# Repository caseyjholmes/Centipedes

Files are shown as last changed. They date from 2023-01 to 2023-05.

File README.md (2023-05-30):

# Centipedes
Quad-purpose Manual and CV controlled 1-100 Burst Generator, Voltage Controlled Master Clock, Voltage Controlled Gate Crasher and Voltage Controlled Clock Mult/Divide Eurorack Module with PSI EITHER WAY power in 4HP.

The module utilizes a ATMEGA328P micrcontroller. The firmware is included before and after compile. You can program with arduino or AVRISPMKII or ebay clone.

Do not populate R19. You can if you want, but it's not necessary. 
Otherwise, this is a straight forward Eurorack format synthesizer module build. 

Enjoy! 
-Casey

5-22-2023 update
Centipedes will now be taking on four individual modes that work with the posted PCB. I will be posting four software routines for each. 
The first of which is a new Centipedes V3 Firmware. It will be uploaded today 5-22-23

There is now one mode for each software file set. No more easter eggs or hidden features. Each mode is stand alone face value. No menus or bugs.

Panels will be provided for each alternate software mode  

The first and updated software mode is NOW posted above on this page.                                                                             
The second, "Centipedes Voltage Controlled Matser Clock" and its associated front panel, is NOW available here:                                                                     
https://github.com/caseyjholmes/Centipedes_Master_Clock

The third mode, "Centipedes Voltage Controled Gate Crasher" and its associated alternate front panel is NOW available here:                                                                   
https://github.com/caseyjholmes/Centipedes_Gate_Crasher

The fourth mode, "Centipedes Voltage Controlled Clock Divider Multiplier" is SOON to be available here:                                                             
https://github.com/caseyjholmes/Centipedes_Clock_Mult_Div

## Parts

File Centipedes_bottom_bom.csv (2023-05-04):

Comment | Designator | Footprint | LCSC Part #
1M | IC1 R11 | R0603
1k | R15 | R0603
2.2k bead | L1 | 0603
10K | R1 | R0603
10k | R12 R14 R16 | R0603
10n | C5 C6 | C0603K
18p | C11 C12 | C0603K
20MHZ | Q1 | HC49UP
22uf | C1 C2 C8 | PANASONIC_C
100k | R2 R3 R4 R5 R6 R7 R8 R9 R10 R13 | R0603
100n | C3 C7 C10 C13 C14 | C0603K
470n | C4 | C0603K
3904 | T1 T2 | SOT23-BEC
ATMEGA328P-AU | IC4 | TQFP32-08
MB1S | D1 | SOIC-4
MCP6002 | IC3 | SO08
REG1117 5.0V | IC2 | SOT223

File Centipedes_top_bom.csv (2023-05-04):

Comment | Designator | Footprint | LCSC Part #
10k | R19 | R0603
200r | R17 R18 | R0603

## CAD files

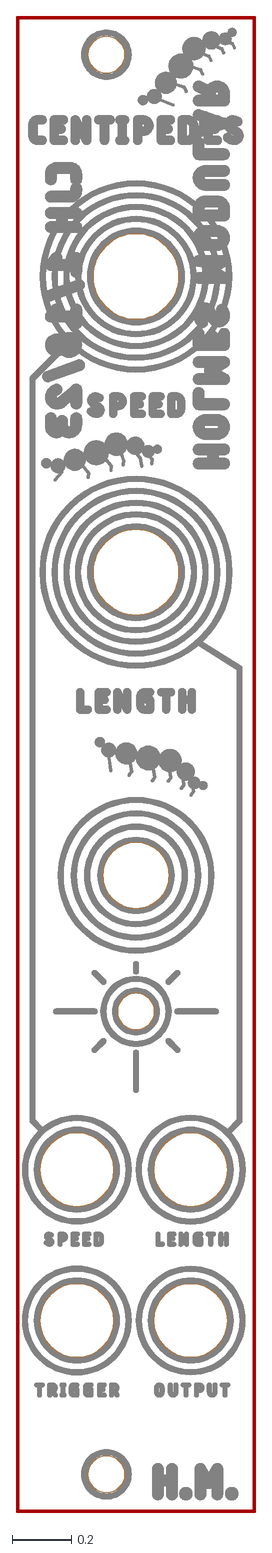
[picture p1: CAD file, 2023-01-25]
Centipedes PANEL.dxf
0.81 x 5.06

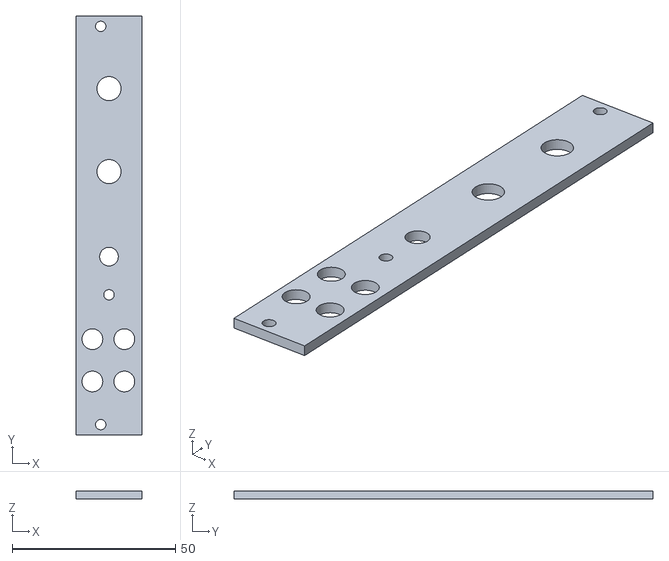
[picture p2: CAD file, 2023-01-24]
3d printable panel centi.stl
20.3 x 128.3 x 2.54

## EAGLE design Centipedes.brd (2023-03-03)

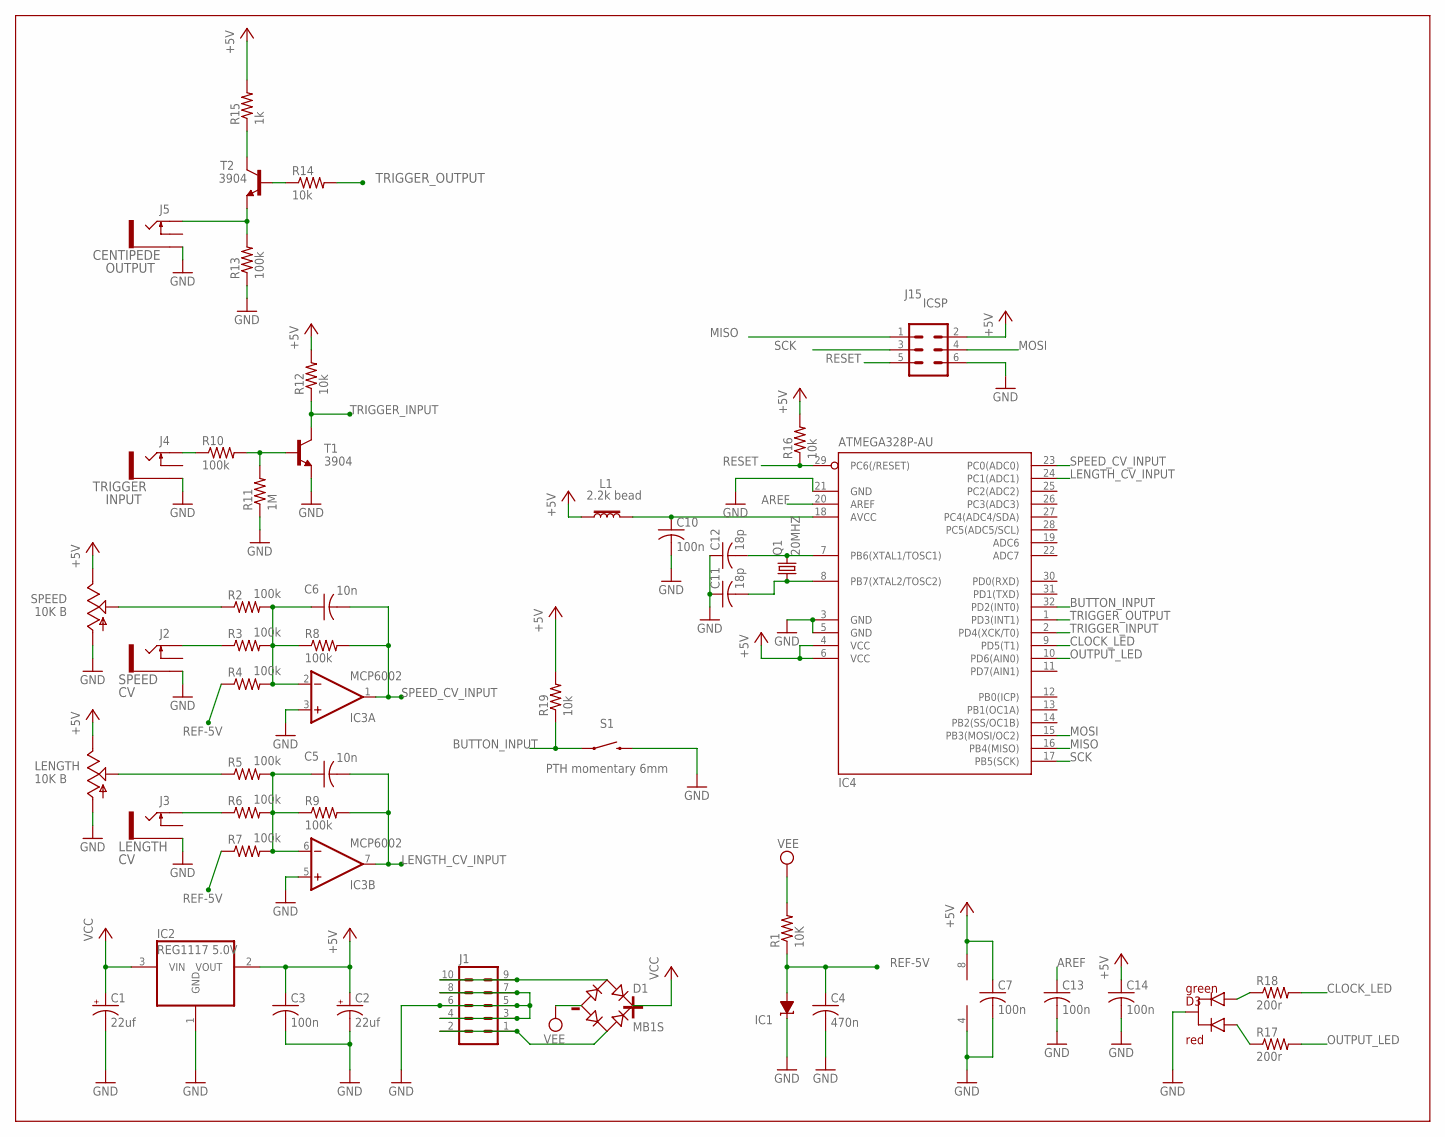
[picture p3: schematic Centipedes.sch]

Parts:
C1, C2: 22uf; PANASONIC_C
C3, C7, C10, C13, C14: 100n; C0603K
C4: 470n; C0603K
C5, C6: 10n; C0603K
C11, C12: 18p; C0603K
D1: MB1S; SOIC-4
D3: LED-DUALCOLOR3MM-THROUGH-HOLE; LED-DUALCOLOR-3MM
IC1: LM4041A12DBZ; DBZ_R-PDSO-G3
IC2: REG1117 5.0V; SOT223
IC3: MCP6002; SO08
IC4: ATMEGA328P-AU; TQFP32-08
J1: MA05-2
J2, J3, J4, J5: THONKICONNNEW; WQP-PJ301M-12_JACK
J15: ICSP; MA03-2
L1: 2.2k bead; 0603
LENGTH: 10K B; 9MM_SNAP-IN_POT
Q1: 20MHZ; HC49UP
R1: 10K; R0603
R2, R3, R4, R5, R6, R7, R8, R9, R10, R13: 100k; R0603
R11: 1M; R0603
R12, R14, R16, R19: 10k; R0603
R15: 1k; R0603
R17, R18: 200r; R0603
S1: PTH momentary 6mm; TACTILE_SWITCH_PTH_6.0MM
SPEED: 10K B; 9MM_SNAP-IN_POT
T1, T2: 3904; SOT23-BEC

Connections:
+5V: C2.+, C3.1, C7.1, C14.1, IC2.2 (VOUT), IC3.8 (V+), IC4.4 (VCC), IC4.6 (VCC), J15.2, L1.1, LENGTH.3 (E), R12.2, R15.2, R16.2, R19.2, SPEED.3 (E)
AREF: C13.1, IC4.20 (AREF)
BUTTON_INPUT: IC4.32 (PD2(INT0)), R19.1, S1.1
CLOCK_LED: IC4.9 (PD5(T1)), R18.2
GND: C1.-, C2.-, C3.2, C4.2, C7.2, C10.2, C11.1, C12.1, C13.2, C14.2, D3.K, IC1.1 (C), IC2.1 (GND), IC3.3 (+IN), IC3.4 (V-), IC3.5 (+IN), IC4.3 (GND), IC4.5 (GND), IC4.21 (GND), J1.3, J1.4, J1.5, J1.6, J1.7, J1.8, J2.P$3_SLEEVE (SLEEVE), J3.P$3_SLEEVE (SLEEVE), J4.P$3_SLEEVE (SLEEVE), J5.P$3_SLEEVE (SLEEVE), J15.6, LENGTH.1 (A), R11.1, R13.1, S1.3 (2), SPEED.1 (A), T1.E; also elsewhere on the board
LENGTH_CV_INPUT: C5.2, IC3.7 (OUT), IC4.24 (PC1(ADC1)), R9.2
MISO: IC4.16 (PB4(MISO)), J15.1
MOSI: IC4.15 (PB3(MOSI/OC2)), J15.4
unnamed: LENGTH.2 (S), R5.1
unnamed: C5.1, IC3.6 (-IN), R5.2, R6.2, R7.2, R9.1
unnamed: J3.P$1_TIP (TIP), R6.1
unnamed: D1.~2 (AC2), J1.1, J1.2
unnamed: D1.~1 (AC1), J1.9, J1.10
unnamed: J4.P$1_TIP (TIP), R10.1
unnamed: C6.1, IC3.2 (-IN), R2.2, R3.2, R4.2, R8.1
unnamed: R10.2, R11.2, T1.B
unnamed: J2.P$1_TIP (TIP), R3.1
unnamed: R2.1, SPEED.2 (S)
unnamed: J5.P$1_TIP (TIP), R13.2, T2.E
unnamed: R15.1, T2.C
unnamed: R14.1, T2.B
unnamed: C12.2, IC4.7 (PB6(XTAL1/TOSC1)), Q1.2
unnamed: C11.2, IC4.8 (PB7(XTAL2/TOSC2)), Q1.1
unnamed: D3.A1, R18.1
unnamed: C10.1, IC4.18 (AVCC), L1.2
unnamed: D3.A2, R17.1
OUTPUT_LED: IC4.10 (PD6(AIN0)), R17.2
REF-5V: C4.1, IC1.2 (A), R1.1, R4.1, R7.1
RESET: IC4.29 (PC6(/RESET)), J15.5, R16.1
SCK: IC4.17 (PB5(SCK)), J15.3
SPEED_CV_INPUT: C6.2, IC3.1 (OUT), IC4.23 (PC0(ADC0)), R8.2
TRIGGER_INPUT: IC4.2 (PD4(XCK/T0)), R12.1, T1.C
TRIGGER_OUTPUT: IC4.1 (PD3(INT1)), R14.2
VCC: C1.+, D1.+, IC2.3 (VIN)
VEE: D1.-, R1.2; also elsewhere on the board

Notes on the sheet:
TRIGGER
SPEED
LENGTH
CENTIPEDE
OUTPUT
INPUT
red
green

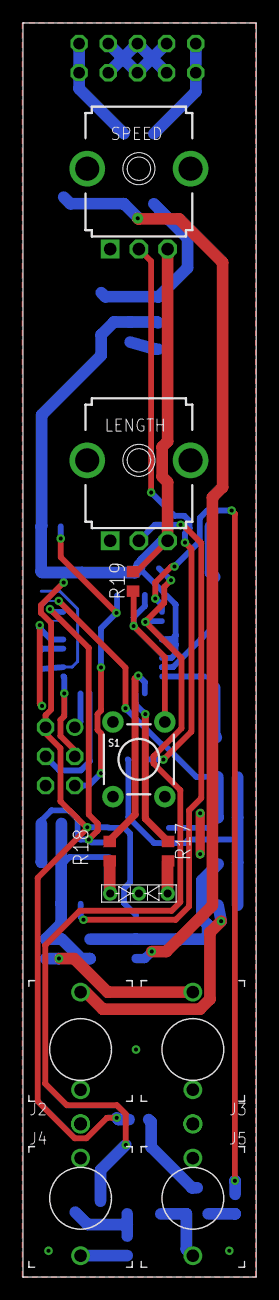
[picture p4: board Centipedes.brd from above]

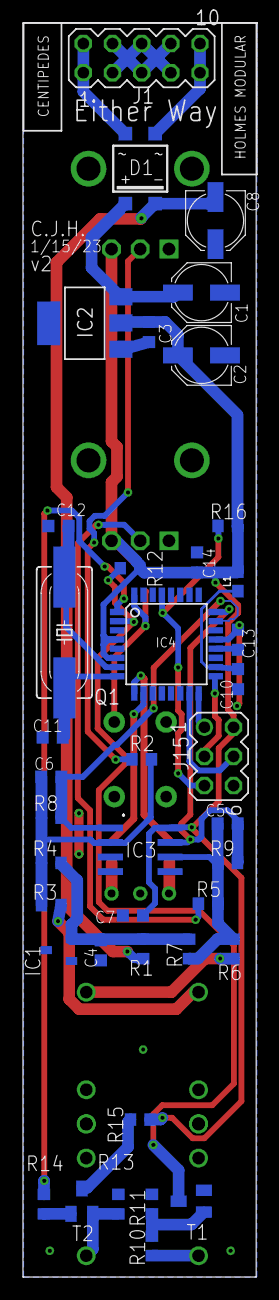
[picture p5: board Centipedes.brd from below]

Board: 2 copper layers, 20.3 x 109.2 mm, 51 parts (40 on the bottom side), 35 nets.

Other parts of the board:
C8: 22uf; PANASONIC_C

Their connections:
GND: C8.+; also elsewhere on the board
VEE: C8.-; also elsewhere on the board

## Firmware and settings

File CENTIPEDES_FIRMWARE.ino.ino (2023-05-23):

//CASEY HOLMES - HOLMES MODULAR - "CENTIPEDES" REV3 - 5/21/23

//constants
const int buttonPin = 2;                       //button pin
const int output = 3;                          //output transistor on pin 3
const int outputLed = 6;                       //red output LED
const int clockLed =  5;                       //green clock led
const int clockPin = 4;                        //clock input transistor pin
long debounce = 20;                            //debounce time no flicker

// Variables
int buttonVal = 0;                             //variable to store current state of the button, usable in interrupt 
int buttonLast = 0;                            //variable to store last state of button
int clockState = 0;                            //variable to store current clock status
int buttonState = 0;                           //varable to store current state of button
bool isOn = true;                              //variable to store state of master duty clock cycle
long btnDnTime;                                //time button was pressed down
long btnUpTime;                                //time button was released
boolean ignoreUp = false;                      //weather ignore button release because press + hold was triggered
unsigned long loopspot = 0;                    //loops pot read variable
unsigned long speedpot =0;                     //speed pot read variable

void setup() {
pinMode(buttonPin, INPUT_PULLUP);              //initialize the pushbutton pin as an input with a internal pullup resistor
pinMode(output, OUTPUT);                       //initialize output transistor
pinMode(outputLed, OUTPUT);                    //initialize output LED as output
digitalWrite(outputLed, 0);                    //initialize output LED as off
pinMode(clockLed, OUTPUT);                     //initialize the LED pin as an output:
digitalWrite(clockLed, 0);                     //initialize cock LED as off
pinMode(clockPin, INPUT);                      //initialize clock pin as input
}

//function for button pressed (triggering a single centipede)
void shortpress() {                            //button was momentarily pressed
digitalWrite(outputLed, 1);                    //turn on LED green indicating button press.
digitalWrite(clockLed, 1);                     //turn on the other color LED
loopspot = map(analogRead(A1), 0, 1023, 100, 1);//read and map pot on A1 into loopspot variable
for (int b = 0; b < loopspot; b++) {           //run for loop for loopspot amount of times
    speedpot = map(analogRead(A0), 0, 1023, 5, 1000);//read and scale Analog 0 into speedpot
    digitalWrite(outputLed, 0);                //turn on output led
    digitalWrite(output, 1);                   //turn on output
    delay(speedpot);                           //wait here for length of speed pot variable
    digitalWrite(outputLed, 1);                //turn off the output LED
    digitalWrite(output, 0);                   //turn off the output
    delay(speedpot);                           //wait here for length of speed pot variable
    }
digitalWrite(outputLed, 0);                    //keep red output led off
digitalWrite(output, 0);                       //turn off the output
digitalWrite(clockLed, 0);                     //keep the red clock output led off
}

void loop() {
clockState = digitalRead(clockPin);                        //read the clock input pin    
while(clockState){                                         //while the clock input that is held low is low..  
  buttonVal = digitalRead(buttonPin);                      //read the pushbutton input pin:
  clockState = digitalRead(clockPin);                      //read the clock input pin
  
//button handler-----------------------------------------------------------------------------------------------------------------------------------------------------------------
if (buttonVal == LOW && buttonLast == HIGH && (millis() - btnUpTime) > long(debounce)) { //test for button press and store down time
   btnDnTime = millis();
   shortpress();         //this was enabled. it triggers cetipede when button is pressed 
}  
if (buttonVal == HIGH && buttonLast == LOW && (millis() - btnDnTime) > long(debounce)) {  //test for button release and store up time
   if (ignoreUp == false) {
      //shortpress();     //this was disabled. it triggers centipede when button is released
      } else {
      ignoreUp = false;
      btnDnTime = millis();
      }
}  
//if (buttonVal == LOW && (millis() - btnDnTime) > long(holdTime)) {//test for button held longer than hold time                           ....disabled for now (easter egg removed)
  // buttonState = !buttonState;                                    //invert state of button variable, trigger master clock routine
   //ignoreUp = true;
   //btnDnTime = millis();
//}  
buttonLast = buttonVal;                                    //update last button state memory for button handler routine

//clock input handler routine----------------------------------------------------------------------------------------------------------------------------------------------------
if (!clockState) {                                         //if clock input pin goes HIGH (clock has gone HIGH again)      
    digitalWrite(outputLed, 1);                            //turn on green led for duration of cycle indicating trigger press
    digitalWrite(clockLed, 1);                             //Turn on red LED
    loopspot = map(analogRead(A1), 0, 1023, 100, 1);       //read and map pot on A1 into loopspot variable
    for (int i = 0; i < loopspot; i++) {                   //run for loop for loopspot amount of times
         speedpot = map(analogRead(A0), 0, 1023, 5, 1000); //read and map pot on A into speed pot variable    
         digitalWrite(clockLed, 0);                        //turn on red clock output LED
         digitalWrite(output, 1);                          //turn on output
         delay(speedpot);                                  //wait here for length of speed pot variable
         digitalWrite(clockLed, 1);                        //turn off red clock output led
         digitalWrite(output, 0);                          //turn off output
         delay(speedpot);                                  //wait here for length of speed pot variable
         }
    }
}
digitalWrite(clockLed, 0);                                 //keep the red clock output led off when not in use
digitalWrite(output, 0);                                   //keep the output off when not in use
digitalWrite(outputLed, 0);                                //keep green output led off when not in use (placing these here turns everything off when not being used)
}

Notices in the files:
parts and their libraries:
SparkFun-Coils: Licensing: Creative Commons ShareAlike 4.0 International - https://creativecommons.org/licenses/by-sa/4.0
